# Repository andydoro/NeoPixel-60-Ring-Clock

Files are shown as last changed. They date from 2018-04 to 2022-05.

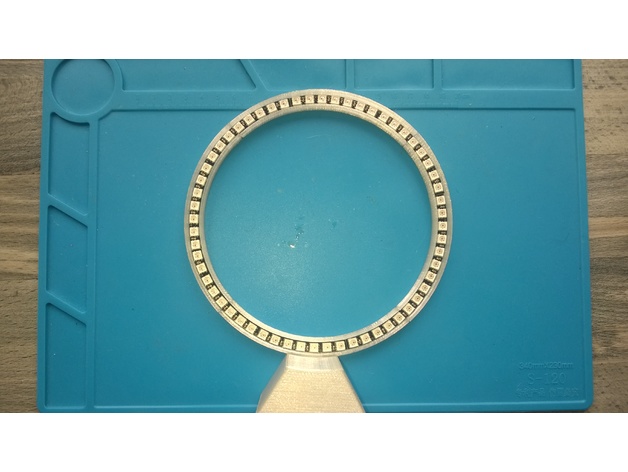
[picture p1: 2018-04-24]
3D enclosure/images/22dce6c2f3b7f5bc79e17c8bd498e20f_preview_featured.jpg

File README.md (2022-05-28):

NeoPixel 60 Ring Clock
======================

For more information visit:

http://andydoro.com/ringclock/ \
[Adafruit Learn Guide](https://learn.adafruit.com/neopixel-60-ring-clock/)

This project uses the DS1307 Real Time Clock with an Arduino to display the time as a series of colored arcs.

With the NeoPixel 60 Ring, we have a perfect display for presenting the time with RGB LEDs!

Hours are represented by red, minutes by green, seconds by blue. The arcs overlap and the colors mix. Minutes and seconds are each represented by a single green or blue LED, respectively. In the 12 hour version, a single red LED represent 24 minutes.

Hardware
-------

* 4 x NeoPixel 1/4 60 Ring - so you can make a NeoPixel 60 Ring
* DS1307 Real Time Clock breakout board
* Arduino Uno or other Arduino compatible microcontroller. This will even work with the Trinket 5V!
* Adafruit Perma-Proto Half-sized Breadboard PCB

If you are new to microcontrollers and Arduino, I would recommend starting out by building the circuit using the Arduino Uno and a breadboard.

If you are more familiar with Arduino, you can use a Trinket 5V and perfboard to build a more permanent electronics project.

Software
-------

Required libraries:

* [Adafruit_NeoPixel](https://github.com/adafruit/Adafruit_NeoPixel)
* [RTClib](https://github.com/adafruit/RTClib)
* [DST_RTC](https://github.com/andydoro/DST_RTC)

3D enclosure created by [arradan](https://www.thingiverse.com/arradan/about)

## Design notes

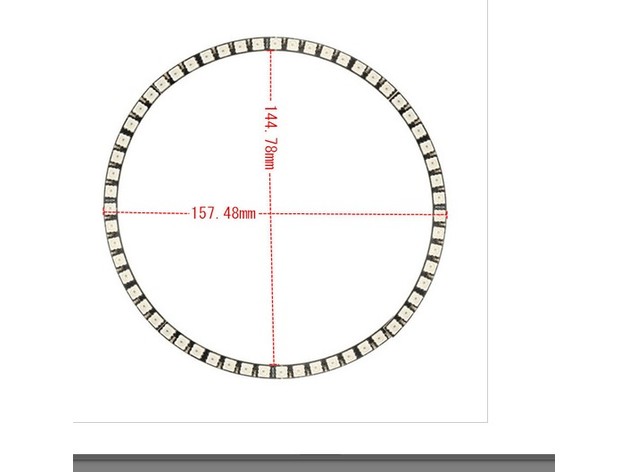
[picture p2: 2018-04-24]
3D enclosure/images/c4b5dcd4da751cd00d1ae3eba0c92fd1_preview_featured.jpg

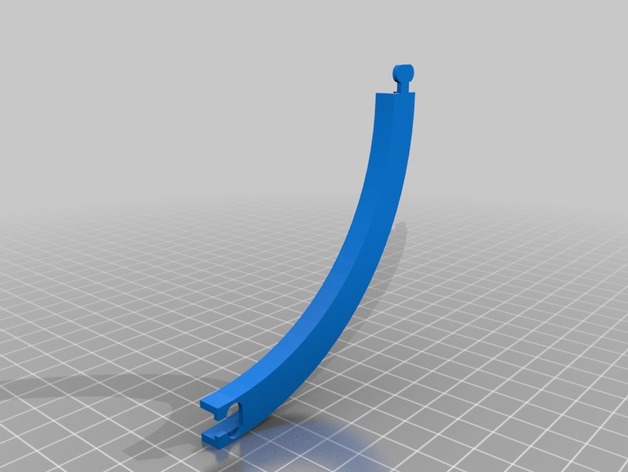
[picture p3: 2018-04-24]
3D enclosure/images/5bc9c06891f443d6b0ef26026fb2811c_preview_featured.jpg

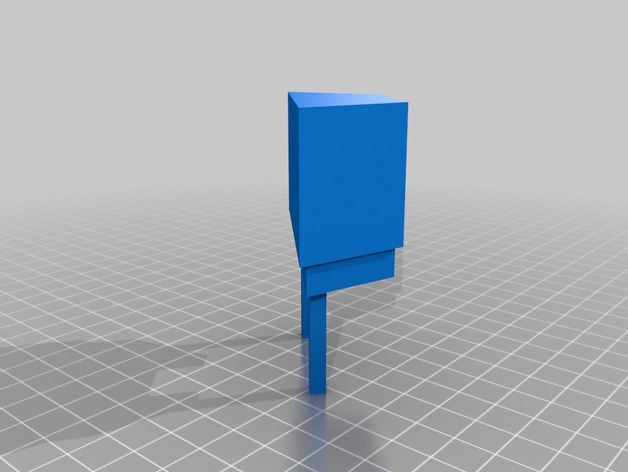
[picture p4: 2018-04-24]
3D enclosure/images/6d6008072107c3be835fff005facc976_preview_featured.jpg

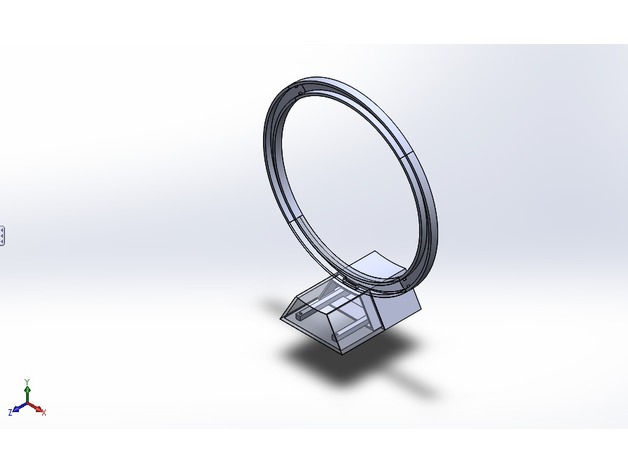
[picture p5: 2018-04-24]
3D enclosure/images/c7da2202001ef3739c67954b4c9dbb31_preview_featured.jpg

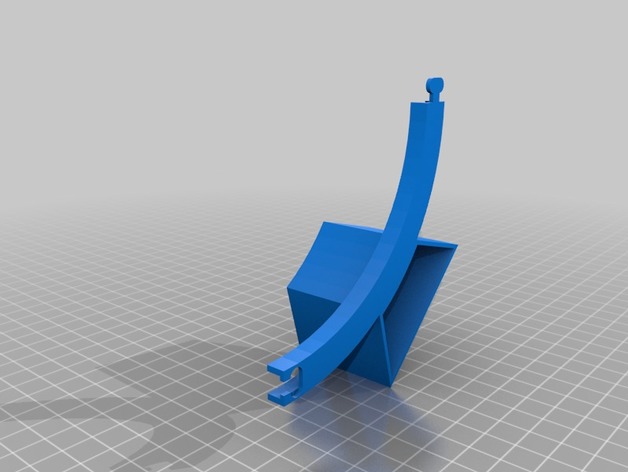
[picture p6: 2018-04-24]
3D enclosure/images/37e0972399dbdf9ed80ed566ae9276be_preview_featured.jpg

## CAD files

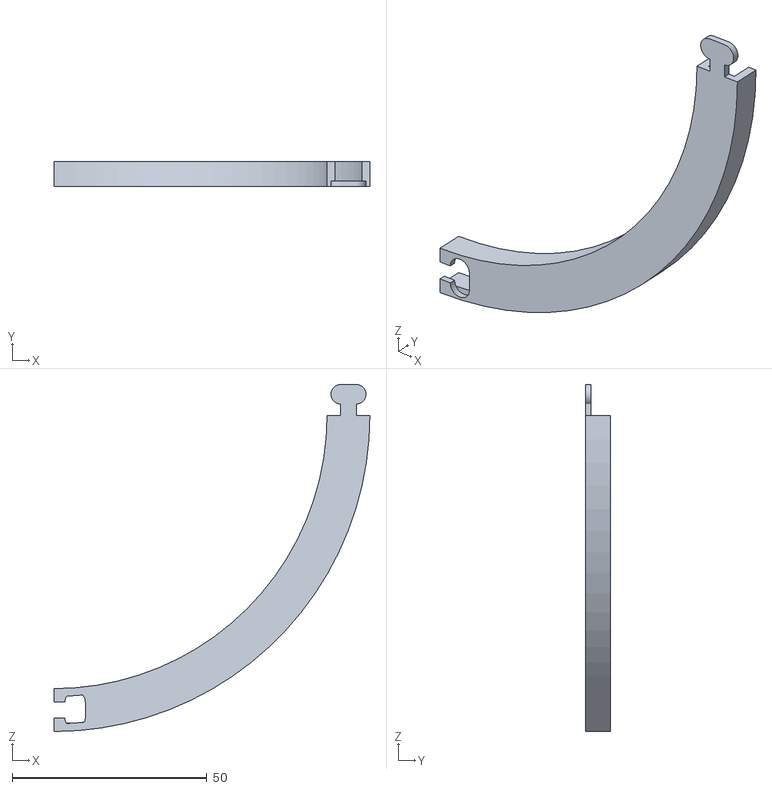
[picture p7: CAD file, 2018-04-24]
3D enclosure/files/tronçon_horloge.STL
81.0 x 6.50 x 89.0

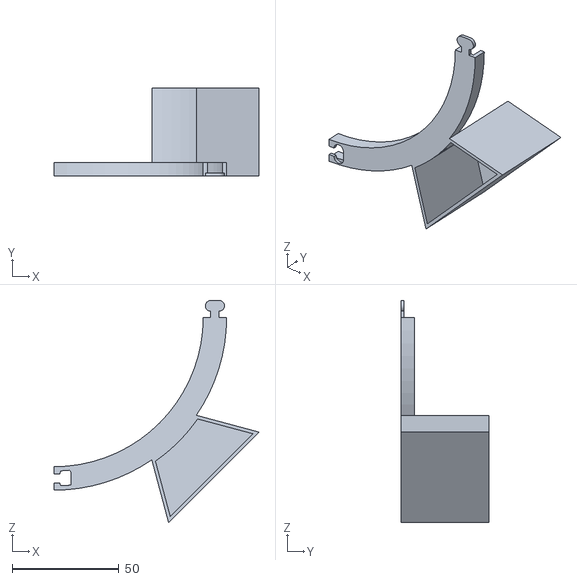
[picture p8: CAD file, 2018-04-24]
3D enclosure/files/tronçon_base.STL
96.2 x 41.5 x 104.2

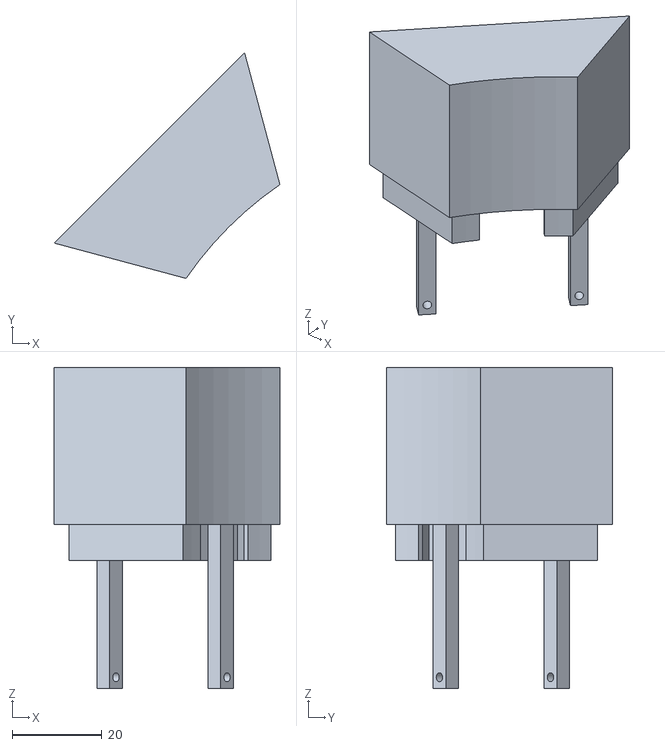
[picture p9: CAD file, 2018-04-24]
3D enclosure/files/couvercle_horloge.STL
50.3 x 50.3 x 71.5

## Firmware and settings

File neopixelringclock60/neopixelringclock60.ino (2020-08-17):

/**************************************************************************
 *                                                                       *
     NeoPixel Ring Clock
     by Andy Doro (mail@andydoro.com)
     http://andydoro.com/ringclock/
 *                                                                      *
 **************************************************************************


   Revision History

   Date      By    What
   20140320  AFD   First draft
   20160105  AFD   Faded arcs
   20160916  AFD   Trinket compatible
   20170727  AFD   added STARTPIXEL for 3D enclosure, variable starting point, added automatic DST support
   20180424  AFD   using DST library https://github.com/andydoro/DST_RTC
   20181231  AFD   nighttime dimming
*/

// include the library code:
#include <Wire.h>
#include <RTClib.h>
#include "DST_RTC.h" // download from https://github.com/andydoro/DST_RTC

#include <Adafruit_NeoPixel.h>

// define pins
#define NEOPIN 3

#define STARTPIXEL 0 // where do we start on the loop? use this to shift the arcs if the wiring does not start at the "12" point

RTC_DS1307 rtc; // Establish clock object
DST_RTC dst_rtc; // DST object

// Define US or EU rules for DST comment out as required. More countries could be added with different rules in DST_RTC.cpp
const char rulesDST[] = "US"; // US DST rules
// const char rulesDST[] = "EU";   // EU DST rules

Adafruit_NeoPixel strip = Adafruit_NeoPixel(60, NEOPIN, NEO_GRB + NEO_KHZ800); // strip object

byte pixelColorRed, pixelColorGreen, pixelColorBlue; // holds color values

// nighttime dimming constants
// brightness based on time of day- could try warmer colors at night?
#define DAYBRIGHTNESS 64
#define NIGHTBRIGHTNESS 20

// cutoff times for day / night brightness. feel free to modify.
#define MORNINGCUTOFF 7  // when does daybrightness begin?   7am
#define NIGHTCUTOFF 22 // when does nightbrightness begin? 10pm


void setup () {
  Wire.begin();  // Begin I2C
  rtc.begin();   // begin clock

  //Serial.begin(9600);
  // set pinmodes
  pinMode(NEOPIN, OUTPUT);

  if (! rtc.isrunning()) {
    //    Serial.println("RTC is NOT running!");
    // following line sets the RTC to the date & time this sketch was compiled
    rtc.adjust(DateTime(__DATE__, __TIME__));
    // DST? If we're in it, let's subtract an hour from the RTC time to keep our DST calculation correct. This gives us
    // Standard Time which our DST check will add an hour back to if we're in DST.
    DateTime standardTime = rtc.now();
    if (dst_rtc.checkDST(standardTime) == true) { // check whether we're in DST right now. If we are, subtract an hour.
      standardTime = standardTime.unixtime() - 3600;
    }
    rtc.adjust(standardTime);
  }


  strip.begin();
  //strip.show(); // Initialize all pixels to 'off'

  strip.setBrightness(DAYBRIGHTNESS); // set brightness

  // startup sequence
  delay(500);
  colorWipe(strip.Color(255, 0, 0), 20); // Red
  colorWipe(strip.Color(0, 255, 0), 20); // Green
  colorWipe(strip.Color(0, 0, 255), 20); // Blue
  delay(500);

}

void loop () {

  // get time
  DateTime theTime = dst_rtc.calculateTime(rtc.now()); // takes into account DST

  byte secondval = theTime.second();  // get seconds
  byte minuteval = theTime.minute();  // get minutes
  int hourval = theTime.hour();   // get hours

  // change brightness if it's night time
  // check less often, once per minute
  if (secondval == 0) {
    if (hourval < MORNINGCUTOFF || hourval >= NIGHTCUTOFF) {
      strip.setBrightness(NIGHTBRIGHTNESS);
    } else {
      strip.setBrightness(DAYBRIGHTNESS);
    }
  }

  hourval = hourval % 12; // This clock is 12 hour, if 13-23, convert to 0-11`

  hourval = (hourval * 60 + minuteval) / 12; //each red dot represent 24 minutes.

  // arc mode
  for (uint8_t i = 0; i < strip.numPixels(); i++) {

    if (i <= secondval) {
      // calculates a faded arc from low to maximum brightness
      pixelColorBlue = (i + 1) * (255 / (secondval + 1));
      //pixelColorBlue = 255;
    }
    else {
      pixelColorBlue = 0;
    }

    if (i <= minuteval) {
      pixelColorGreen = (i + 1) * (255 / (minuteval + 1));
      //pixelColorGreen = 255;
    }
    else {
      pixelColorGreen = 0;
    }

    if (i <= hourval) {
      pixelColorRed = (i + 1) * (255 / (hourval + 1));
      //pixelColorRed = 255;
    }
    else {
      pixelColorRed = 0;
    }

    strip.setPixelColor((i + STARTPIXEL) % 60, strip.Color(pixelColorRed, pixelColorGreen, pixelColorBlue));
  }

  //display
  strip.show();

  // printTheTime(theTime);

  // wait
  delay(100);

}


// Fill the dots one after the other with a color
void colorWipe(uint32_t c, uint8_t wait) {
  for (uint16_t i = 0; i < strip.numPixels(); i++) {
    //strip.setPixelColor(i, c);
    strip.setPixelColor((i + STARTPIXEL) % 60, c);
    strip.show();
    delay(wait);
  }
}

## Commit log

2016-05-14 Fix deprecated conversion warning
    Fix for "warning: deprecated conversion from string constant to ‘char*’" error. Any functions into which you pass string literals should use 'char const *' as the type instead of 'char*'
2016-09-16 made Trinket compatible
    made compatible with Trinket 5V
2018-04-24 3D enclosure added
    3D enclosure added
    [couvercle_horloge.STL, tronçon_base.STL, tronçon_horloge.STL]
2019-01-08 corrected info
    corrected enclosure attribution
